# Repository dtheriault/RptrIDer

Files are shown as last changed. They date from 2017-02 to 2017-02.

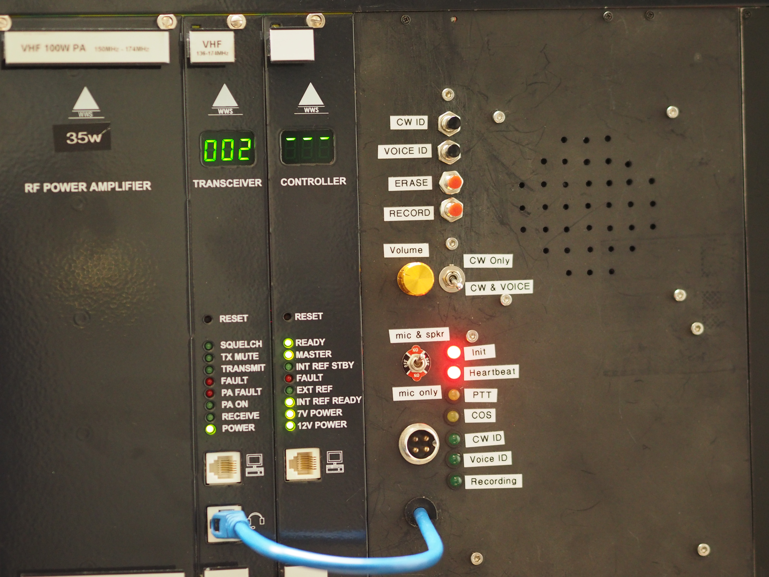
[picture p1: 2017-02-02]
Pics/P2020010.JPG

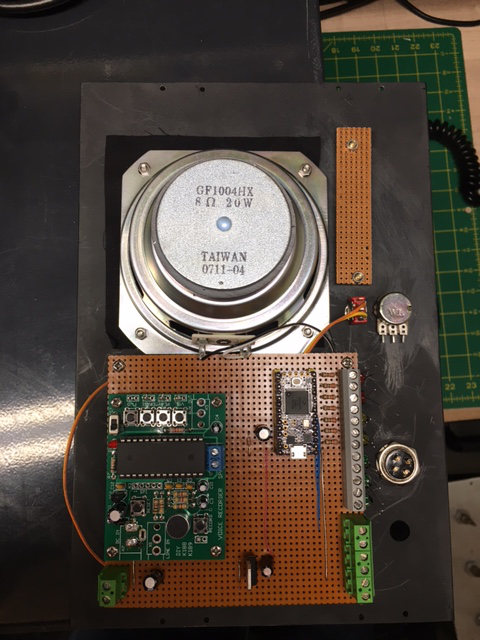
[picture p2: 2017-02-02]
Pics/IMG_0762.JPG

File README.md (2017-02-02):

# RptrIDer

Teensy3.2 Based Repeater Controller

This is a very simplistic repeater controller I built for Sherwin WB7NFX.
Included in the project is manual, schematic, eagle board files and the
Arduino sketch file for a Teensy3.2 board.

The repeater controller was designed to interface to a Westel DRB25 VHF
repeater.  This repeater did not have capability to ID per FCC Part 97 rules
and since the machine was to be used on the 2m ham band, this was a must.

Sherwin wanted the repeater to generate a Voice ID and provided me with a
small PCB that performed audio recording and playback.  I decided to build up
this board and have it controlled by a small ATtiny85 processor.  Shortly I
wanted to add CW support and have more input/outputs for buttons and LED's
so moved to an Teensy3.2 board I had purchased but had not found a project
to use it with.  A repeater controller seemed ideal.

Front panel was to have LED's to indicate status of the repeater and
controller operations.  When PTT, CW ID, Voice ID, Carrier Detect and status
for when the Voice Recording is erased or recorded.  There's also a heartbeat
and init status LED.

Interface to the repeater is via an RJ45 jack on the transceiver card.
There was an empty set of slots in the chassis for me to add a panel, speaker
microphone jack, LED's, buttons and switches and a volume control.  It also
mounts a home brew PCB that houses the Teensy and Voice ID boards.

The board is very simple 3 channel audio mixer with header for the Teensy3.2
and a voice ID board.  Uses standard header pins since that's what I had and
allowed me to debug this on the desk vs. connected to the repeater.

The Teensy3.2 is responsible for time keeping, generating a CW ID, detecting
inputs such as PTT, and front panel buttons and implements simplistic Carrier
Detect to know when the repeater is in use.  Westel did not have COS line
for me to use.  Power for the board is supplied by the transceiver card and
total current at 12v is around 150ma max.

There is a directory with photo's of the project, and if you search on
YouTube you can find a movie of the prototype in use during debug of the
project.

Special thanks goes to SV1DJG, Nick in Greece who developed the CW Beacon
sketch I leveraged into this project.

This project is available via GPL for your use.

Feel free to drop me an email if you have any questions on the project and
I'll try to answer them as best I can.  Please note, the code was quickly
developed and is probably still has a bug or two.

WB7NFX Repeater is operational in Chino Valley Az @ 144.570/145.170 Mhz with
PL of 100.0 Hz.

73,
Doug - NO1D

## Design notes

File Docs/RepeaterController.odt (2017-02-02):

# Introduction

The WB7NFX Repeater Controller is a module designed to support a Westell DRB25 VHF repeater. The controller consists of 3 components, a 2-board module and front panel containing speaker, LED’s and push button controls.

The controller interfaces with the VHF transceiver board via an RJ45 connector. The controller generates CW ID and Voice ID at 10m and 30m intervals respectively. The CW ID interval follows part 97 rules pertaining to Repeater Identification. Power is supplied from the VHF transceiver board.

The controller consists of a 3 channel audio mixer that takes CW, Voice and Microphone feed from the front panel and interfaces to the VHF repeater module via its Microphone input. Levels for each channel are made via trim pots on the controller module.

To maintain time/state information the controller utilizes a small micro-controller called a Teensy3.2 AVR. The micro-controller is responsible for driving PTT to the repeater and generates a Carrier Operated Squelch input to determine repeater activity. The micro-controller drives LED for status indication and senses push button controls from the microphone and push buttons on the front panel. The micro-controller also generates the CW ID which has been programmed via software. Updates to the software can be made via USB interface on the Teensy3.2 sub-module.

When the repeater is idle a Voice ID can be configured to be sent every 30m. When COS is first detected a CW ID is sent at 18wpm and again every 10m while the machine is active.

# Front Panel, Interconnect and Controls

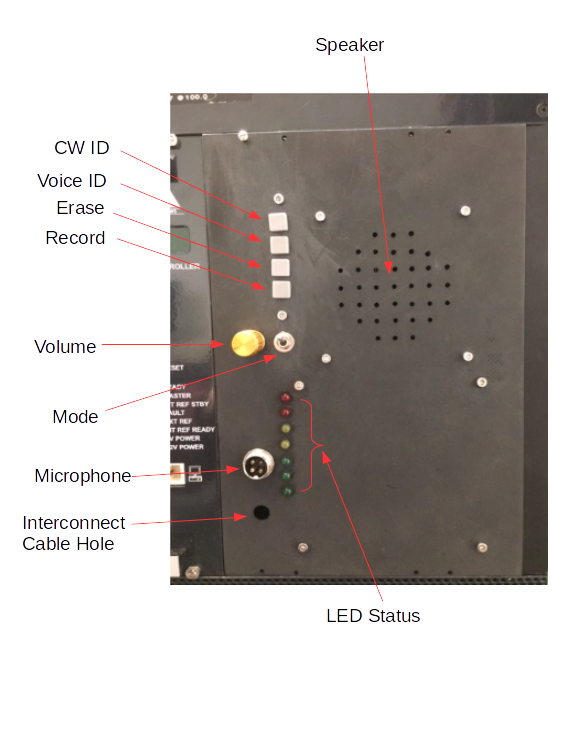
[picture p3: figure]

# Operation

Operation of the controller is simplistic. There are several buttons on the front panel which perform the following operations :

- CW ID – Sends CW ID which has been programmed into the software.
- Voice ID – Sends the Voice ID which has been recorded in the Voice ID board
- Erase – Erases the recorded Voice ID
- Record – Records a new Voice ID. Note that you must first Erase the stored ID before a new one is recorded. Recording of the message uses the front panel microphone however PTT is not required to be pressed.
- Mode – Toggles whether the controller sends CW ID only or Both Voice ID and CW ID. CW ID is sent after the 1st time the repeater goes active then again in 10m per part 97 rule. Voice ID is sent at 30m intervals when the repeater is not active.

The front panel contains a speaker and small audio amplifier with volume control. This allows to hear the repeater activity. When using the front panel microphone to transmit voice is not heard over the speaker.

Note : If using a handheld transceiver and volume is up you may hear feedback unless the microphone has been disconnected from the front panel or the volume is turned down enough to prevent feedback.

Front panel has 7 LED’s that represent status of the controller. They are as follows (top to bottom) :

LED | Description
INIT | Lights up when the setup function completes in software
HEARTBEAT | Pulses approx 1s intervals indicating main loop is operational
PTT | Microphone PTT is active
COS | Repeater Tx is busy, Carrier Operated Squelch via software
CW ID | CW ID is being sent
Voice ID | Voice ID is being sent
Recording | Recording new voice ID in process

# Schematic

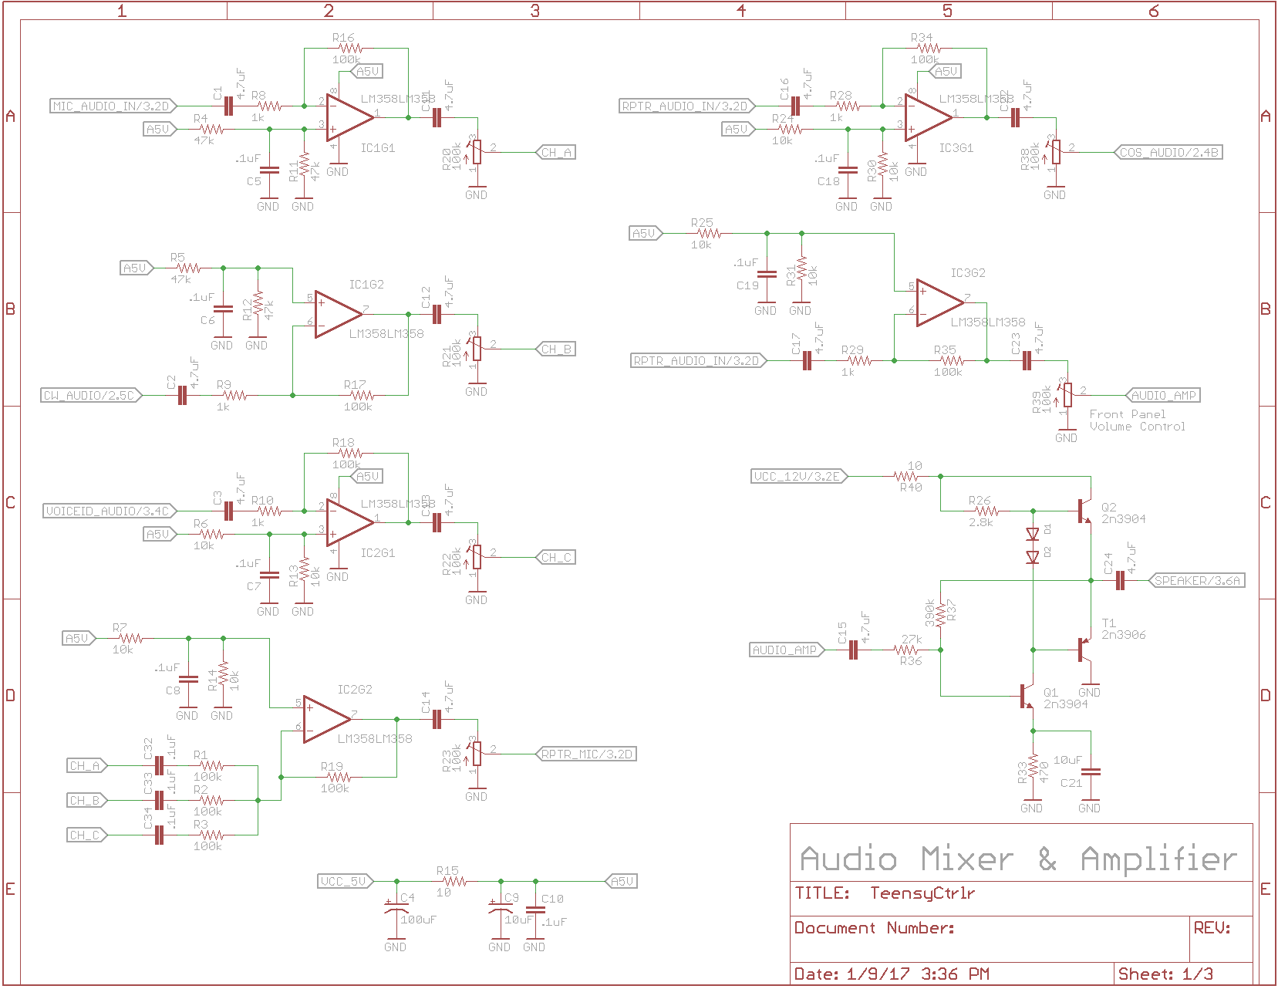
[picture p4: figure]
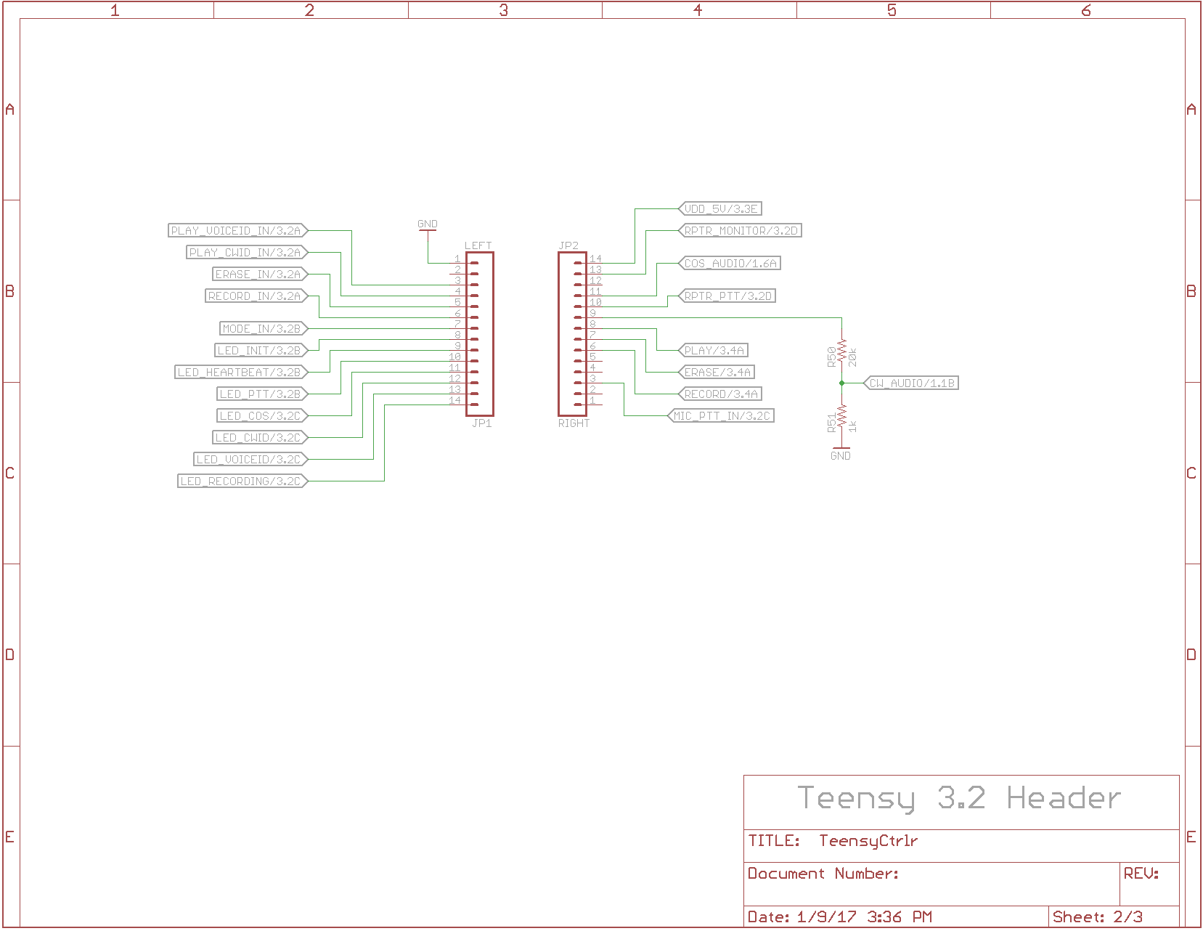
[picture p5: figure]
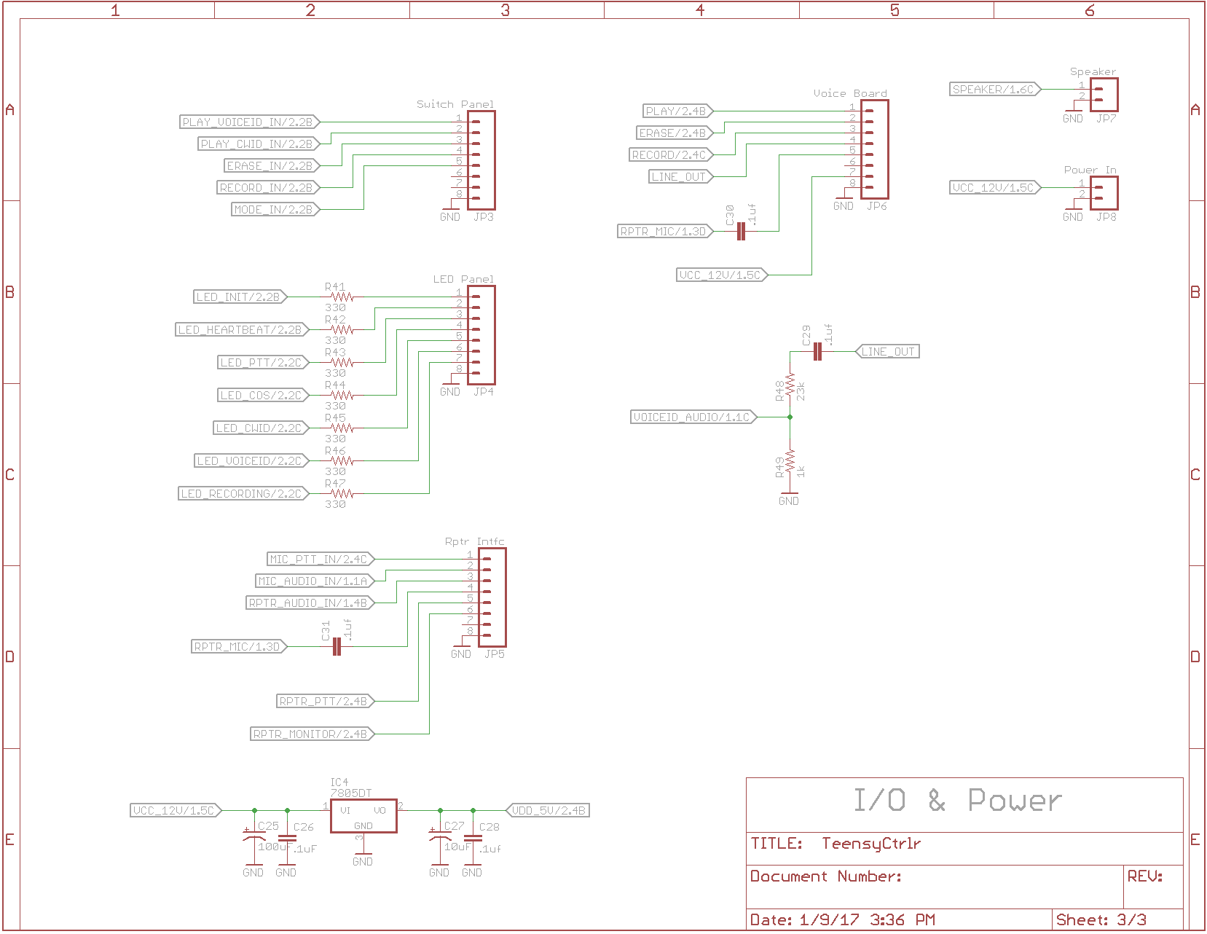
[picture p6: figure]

# Software

Software can be found at : https://github.com/dtheriault/TeensyRptrCtrlr

The software is offered under the GPL and is considered Open Source available for general use and modification following GPL agreement.

Software is written in C langage, and uses the Ardruino IDE supporting the Teensy3.2 AVR chipset.

Updates to the software are made using the micro USB connector on the Teensy3.2 module located on the controller module.

//

// File: TeensyRptrCtrlr.ino

//

// Author: NO1D - Doug Theriault

// Dated: 20170112

//

// Description:

//

// This sketch is a very basic/simple repeater ID controller which was developed

// for WB7NFX. The interface is to a Westel DRB25 VHF repeater however this

// software is generic and can be modified to fit other requirements.

//

// The software handles button presses to activate CW ID, Voice ID and record

// and erase functions and mode switch. In addition it outputs series of 7 LEDs

// to track state/function. It also outputs control lines to a Voice ID board

// and the repeater itself.

//

// Since the Westel Repeater did not have means to detect COS (carrier operated

// squelch) the repeaters audio is fed into a pin configured with ADC so its

// voltage can be read.

//

// The controller was based on Teensy3.2 board. I started with an ATiny85 but

// quickly ran out of pins as I wanted to add more/more features...

//

// References:

//

// The CW ID portion of the code was developed by SV1DJG which was a great start

// for me to get something working on an ATiny85 chip. Special thanks goes out

// to Nick for producing this software. I include his file header below.

//

// Bugs/Issues/ToDo:

//

// Ideally this would all be run off interrupts/timers. Someday perhaps.

// This is not a very powerful repeater controller. While it will ID per part 97

// rules, its been deployed only recently and may still contain bugs.

// There are some printf statements for debugging left in the code and do affect

// accuracy of the timing. You might need to modify delay loops when removing

// them.

//

// Hardware:

//

// Schematic for simple 3-channel audio mixer, 3-transistor audio amp, Teensy I/O

// LED's etc are available on github.

//

// Voice ID is handled by external board similar to:

// https://ludens.cl/Electron/voiceID/voiceID.html

//

// Contact info:

//

// email: no1d.doug@gmail.com

// repository: https://github.com/dtheriault/TeensyRptrCtrlr

//

// License:

//

// Copyright (C) 2017 Douglas Theriault - NO1D

//

// TeensyRptrCtrlr.ino is free software: you can redistribute it and/or modify

// it under the terms of the GNU General Public License as published by

// the Free Software Foundation, either version 3 of the License, or

// (at your option) any later version.

//

// TeensyRptrCtrlr.ino is distributed in the hope that it will be useful,

// but WITHOUT ANY WARRANTY; without even the implied warranty of MERCHANTABILITY

// or FITNESS FOR A PARTICULAR PURPOSE. See the GNU General Public License for

// more details.

//

// You should have received a copy of the GNU General Public License

// along with IDtimer.ino. If not, see <http://www.gnu.org/licenses/>.

//

//

////////////////////////////////////////////////

//

// A simple CW Blinker (aka LED Beacon)

// by SV1DJG (c.2016)

//

// This is a ultra simple blinker in CW for the

// digispark mini board (attiny85).

// change the led port if using a different

// board (e.g. Arduino)

//

// Just set your message into the msg array and you

// are ready to go.Make sure to use ONLY the set

// of the supported characters.

// the supported set of characters is capital

// letters,numbers and a few symbols.

//

// You can also modify the transmission speed by

// changing the speedWPM variable.

//

// HAVE FUN!!

//

// This code is provided as-is and may contain bugs!

//

// (codesize:1132 bytes + message length)

//

////////////////////////////////////////////////

#include <avr/pgmspace.h>

//

// PIN Definitions: Input and Outputs

//

#define PLAY_VOICE_IN 1 // Send the Voice ID, Play on Voice Bd

#define PLAY_CW_IN 2 // Send a CW ID from the Teensy

#define ERASE_IN 3 // Erase the Voice ID, Erase on Voice Bd

#define RECORD_IN 4 // Record New Voice ID, Record on Voice Bd

#define MODE_IN 5 // Toggle switch for CW only or CW & Voice ID

//

#define LED_INIT 6 // Setup has been executed, stays lit

#define LED_HEARTBEAT 7 // Loop interval, one second pulse

#define LED_PTT 8 // PTT is activated, Microphone front panel

#define LED_COS 9 // COS detected from Repeater Audio feed

#define LED_CWID 10 // CW ID in process

#define LED_VOICEID 11 // Voice ID in process

#define LED_RECORDING 12 // Recording new Voice ID in process

//

#define RPTR_MONITOR 14 // Repeater Monitor Active Low (not used)

#define PTT_IN 15 // Front Panel Microphone, Active Low

//

#define RECORD_OUT 18 // Button on Voice Bd

#define ERASE_OUT 19 // Button on Voice Bd

#define PLAY_OUT 20 // Button on Voice Bd

//

#define CW_AUDIO 21 // PWM Teensy output of CW Audio tone

#define PTT_OUT 22 // PTT to Repeater, Active Low

#define COS_IN 23 // Carrier Detect Input

//

//

//

// General Defines

//

#define CW_TONE 750 // CW ID Tone in Hertz

//

#define MODE_CW_ONLY 0 // Does not play Voice ID

#define MODE_BOTH 1 // Plays both Voice and CW ID's

//

// State Machine Defines

//

#define IDLE 1 // IDLE State

#define TIMING_CW 2 // Timer State: Detected COS/PTT

#define TIMING_VOICE 3 // Timer State: Detected COS/PTT

#define CWID 4 // CW ID: Send CW ID now, timer expired

#define VOICEID 5 // Voice ID: Send Voice ID

#define RPTR_ACTIVE 6 // Time COS/PTT been active

#define ID_FIRST 7 // First ID > 10m on first PTT/COS from IDLE period

//

// Timeouts are in seconds

//

#define CW_TIMEOUT 600 // Play CW ID every 10m after COS or PTT go active

#define VOICE_TIMEOUT 1800 // Play Voice ID every 30m when IDLE

#define COS_TIMEOUT 300 // COS/PTT 3m timeout

#define VID_TIMEOUT 1200 // 20m after CWID, if we're idle, we VoiceID

//

// All delays are in ms

//

#define RECORDING_DELAY 10000 // Record for 10s

#define ERASE_DELAY 10000 // Erase for 10s

#define VOICEID_DELAY 10000 // 10s for voice id to play

#define PTT_DELAY 1500 // 1.5s PTT delay

#define COS_DELAY 100 // delay 100ms between consecutive COS ADC reads

//

#define LED_OFF LOW

#define LED_ON HIGH

#define TRUE 0

#define FALSE 1

// this defines the keying level and provides a quick way to change the keying method.

// when we use a LED we need HIGH to turn the LED on and LOW to turn the LED off

// but if we select to connect an external switching hardware , this may need to be reversed

#define MORSE_KEY_DOWN HIGH

#define MORSE_KEY_UP LOW

// delay before repeating the message (in Ms)

#define repeatDelayMs 300000

// transmission speed (in words per minute)

#define speedWPM 18

// element duration is according to Farnsworth Technique

// see : http://www.arrl.org/files/file/Technology/x9004008.pdf

#define dotDuration 1200 / speedWPM // element duration in milliseconds

#define dashDuration dotDuration * 3

#define interSymbolDuration dotDuration

#define interCharDuration dotDuration * 3

#define interWordDuration dotDuration * 7

//

// Global Variables Here

//

boolean mic_ptt;

boolean play_voice;

boolean play_cw;

boolean erase_voice;

boolean record;

boolean voice_bd_reset;

int mode;

int state;

int last_state;

int cw_timer;

int voice_timer;

int activity_timer;

int last_id;

int cos_in;

boolean last_ptt;

boolean last_cos;

char dState[8][16] =

{

"UNKNOWN",

"IDLE",

"TIMING CW",

"TIMING VOICE",

"CW ID",

"VOICE ID",

"RPTR ACTIVE",

"ID FIRST"

};

//////////////////////////////////////////////////////////////////////////////////////////////

//

// this is the beacon message (only capital letters, numbers and a few symbols - see below)

//

//////////////////////////////////////////////////////////////////////////////////////////////

//char const msg[] = "TEST DE SV1DJG";

char const msg[] = "DE WB7NFX/R";

char const msgTimeout[] = "TIMEOUT";

//

// Morse code table

// ----------------

// Morse code elements are variable length and transmitted Msb first.

// we need to know the length of each element so we save

// it along with the element as the first part of the pair in the table.

//

// Each element is made up from 1's and 0's where:

// 1 means DOT

// 0 mean DASH

// for example, A is DOT-DASH which is translated to 10.

// B is DASH-DOT-DOT-DOT which is translated to 0111 etc.

// these are encoded as binary values and paired with their length

// for example

// A -> 2,B10

// B -> 4,B0111

// etc

//

// table of elements for Morse cose numbers do not follow this as all elements are 5 digits long

// (so we save space in the symbol table)

//

byte const letters[] PROGMEM =

{

2,B10, // A

4,B0111, // B

4,B0101, // C

3,B011, // D

1,B1, // E

4,B1101, // F

3,B001, // G

4,B1111, // H

2,B11, // I

4,B1000, // J

3,B010, // K

4,B1011, // L

2,B00, // M

2,B01, // N

3,B000, // O

4,B1001, // P

4,B0010, // Q

3,B101, // R

3,B111, // S

1,B0, // T

3,B110, // U

4,B1110, // V

3,B100, // W

4,B0110, // X

4,B0100, // Y

4,B0011, // Z

};

byte const numbers[] PROGMEM =

{

B00000, // 0

B10000, // 1

B11000, // 2

B11100, // 3

B11110, // 4

B11111, // 5

B01111, // 6

B00111, // 7

B00011, // 8

B00001, // 9

};

byte const symbols[] PROGMEM =

{

6,B101010, // Full-stop (period)

6,B001100, // Comma

6,B110011, // Question mark (query)

5,B01101 , // Slash

5,B01110 , // Equals sign

};

// transmits a morse element (either a dot or a dash)

void sendSymbol(boolean sendDot)

{

digitalWrite(LED_CWID, MORSE_KEY_DOWN);

tone(CW_AUDIO, CW_TONE);

delay(sendDot ? dotDuration : dashDuration);

digitalWrite(LED_CWID, MORSE_KEY_UP);

noTone(CW_AUDIO);

}

// transmits an ASCII character in Morse Code

void sendCharacter(char c)

{

byte numberOfBits = 0;

byte elementCode = 0;

if (c >= 'A' && c <='Z')

{

int elementIndex = (int)(c-'A');

numberOfBits = pgm_read_byte(&letters[elementIndex * 2]);

elementCode = pgm_read_byte(&letters[elementIndex * 2 + 1]);

}

else if (c >= '0' && c <='9')

{

int elementIndex = (int)(c-'0');

numberOfBits = 5;

elementCode = pgm_read_byte(&numbers[elementIndex]);

}

else if (c == ' ')

{

// adjust delay because we have already "waited" for a character separation duration

// NOTE:this delay will not be 100% accurate if the first character in the message is SPACE

delay(interWordDuration-interCharDuration);

}

else

{

int elementIndex = -1;

if (c == '.') elementIndex = 0;

else if (c == ',') elementIndex = 1;

else if (c == '?') elementIndex = 2;

else if (c == '/') elementIndex = 3;

else if (c == '=') elementIndex = 4;

if (elementIndex != -1)

{

numberOfBits = pgm_read_byte(&symbols[elementIndex * 2]);

elementCode = pgm_read_byte(&symbols[elementIndex * 2 + 1]);

}

}

if (numberOfBits > 0)

{

byte mask = 0x01 << (numberOfBits - 1);

while (numberOfBits > 0 )

{

sendSymbol((elementCode & mask) == mask);

delay(interSymbolDuration);

mask = mask >> 1;

--numberOfBits;

}

// adjust delay because we have already "waited" for a dot duration

delay(interCharDuration - interSymbolDuration);

}

}

// transmits an ASCII message in Morse Code

void sendCWID(const char* msg)

{

// trigger PTT so we send ID over repeater

digitalWrite(PTT_OUT, LOW);

digitalWrite(LED_PTT, LED_ON);

delay(PTT_DELAY);

while (*msg)

sendCharacter(*msg++);

delay(PTT_DELAY);

// turn off PTT at the end

digitalWrite(PTT_OUT, HIGH);

digitalWrite(LED_PTT, LED_OFF);

}

// transmits Voice ID via external board

void sendVoiceID()

{

Serial.print("Sending Voice ID\n");

digitalWrite(PTT_OUT, LOW);

digitalWrite(LED_PTT, LED_ON);

delay(PTT_DELAY);

digitalWrite(PLAY_OUT, LOW);

digitalWrite(LED_VOICEID, LED_ON);

// TODO: Ideally we want program to continue while output is low

// as believe voice play stops when we toggle back high

delay(VOICEID_DELAY);

digitalWrite(PLAY_OUT, HIGH);

digitalWrite(LED_VOICEID, LED_OFF);

delay(PTT_DELAY);

digitalWrite(PTT_OUT, HIGH);

digitalWrite(LED_PTT, LED_OFF);

Serial.print("End Voice ID\n");

}

//

// Reset the external Voice ID board

//

void resetVoiceBd()

{

// digitalWrite(RESET_OUT, LOW);

delay(500);

// digitalWrite(RESET_OUT, HIGH);

}

//

// Erase stored Voice ID

//

void eraseVoice()

{

digitalWrite(ERASE_OUT, LOW);

delay(ERASE_DELAY);

digitalWrite(ERASE_OUT, HIGH);

Serial.print("Voice ID Erased\n");

}

//

// Record New Voice ID

//

void recordVoiceID()

{

// first erase Voice ID

eraseVoice();

// Enable recording for max of 7 seconds

digitalWrite(LED_RECORDING, LOW);

digitalWrite(RECORD_OUT, LOW);

delay(RECORDING_DELAY);

digitalWrite(RECORD_OUT, HIGH);

// delay a bit between operations

delay(2000);

// Now play without transmitting

digitalWrite(PLAY_OUT, LOW);

delay(VOICEID_DELAY);

// Turn off LED indicator at end of recording

digitalWrite(LED_RECORDING, HIGH);

Serial.print("Voice ID Recorded\n");

}

//

// readCOS()

//

boolean readCOS()

{

int rValue = 0;

rValue = analogRead(COS_IN);

delay(COS_DELAY);

rValue += analogRead(COS_IN);

rValue = rValue/2;

// Serial.printf("COS: %3d\n", rValue);

if (rValue > 30) return HIGH;

return LOW;

}

//

// readInputs()

//

void readInputs()

{

mic_ptt = digitalRead(PTT_IN);

play_voice = digitalRead(PLAY_VOICE_IN);

play_cw = digitalRead(PLAY_CW_IN);

erase_voice = digitalRead(ERASE_IN);

record = digitalRead(RECORD_IN);

mode = digitalRead(MODE_IN);

cos_in = readCOS();

}

//

// execCommands()

//

void execCommands()

{

// Low Priority: Handle Front Panel Buttons

//

if (play_cw == LOW)

state = CWID;

else if (play_voice == LOW)

state = VOICEID;

// if (voice_bd_reset == LOW)

// resetVoiceBd();

if (record == LOW)

recordVoiceID();

else if (erase_voice == LOW)

eraseVoice();

// Med Priority: Handle COS input

//

if (cos_in == HIGH) {

if (last_cos == LOW)

Serial.print("COS Active\n");

last_cos = HIGH;

// light the COS LED

digitalWrite(LED_COS, LED_ON);

}

else {

if (last_cos == HIGH)

Serial.print("COS Deactivated\n");

last_cos = LOW;

digitalWrite(LED_COS, LED_OFF);

}

// High Priority: Handle PTT

//

if (mic_ptt == LOW) {

if (last_ptt == HIGH)

Serial.print("PTT Active\n");

last_ptt = LOW;

digitalWrite(LED_PTT, LED_ON);

digitalWrite(PTT_OUT, LOW);

}

else {

digitalWrite(LED_PTT, LED_OFF);

digitalWrite(PTT_OUT, HIGH);

if (last_ptt == LOW)

Serial.print("PTT Deactivated\n");

last_ptt = HIGH;

}

// Serial.printf("execCmd: [COS]: %d, [PTT]: %d\n", cos_in, mic_ptt);

}

//

// Initialization Function - executed once

//

void setup()

{

int x = 0;

int value = 0;

// Initilize Pins

//

pinMode(PTT_IN, INPUT_PULLUP);

pinMode(PLAY_VOICE_IN, INPUT_PULLUP);

pinMode(PLAY_CW_IN, INPUT_PULLUP);

pinMode(ERASE_IN, INPUT_PULLUP);

pinMode(RECORD_IN, INPUT_PULLUP);

pinMode(MODE_IN, INPUT_PULLUP);

analogReference(DEFAULT);

for (x = 0; x < 100; x++) {

value += analogRead(COS_IN);

}

pinMode(LED_INIT, OUTPUT);

pinMode(LED_HEARTBEAT, OUTPUT);

pinMode(LED_PTT, OUTPUT);

pinMode(LED_COS, OUTPUT);

pinMode(LED_CWID, OUTPUT);

pinMode(LED_VOICEID, OUTPUT);

pinMode(LED_RECORDING, OUTPUT);

// pinMode(CW_AUDIO, ????);

pinMode(PTT_OUT, OUTPUT);

pinMode(PLAY_OUT, OUTPUT);

pinMode(RECORD_OUT, OUTPUT);

pinMode(ERASE_OUT, OUTPUT);

// pinMode(RESET_OUT, OUTPUT);

// preset digital outputs

digitalWrite(PTT_OUT, HIGH);

digitalWrite(PLAY_OUT, HIGH);

digitalWrite(RECORD_OUT, HIGH);

digitalWrite(ERASE_OUT, HIGH);

// Initialize State Machine to IDLE

//

state = IDLE;

last_state = DEFAULT;

// Voice_Bd_Reset the timer counts

//

cw_timer = CW_TIMEOUT;

voice_timer = VOICE_TIMEOUT;

activity_timer = COS_TIMEOUT;

last_id = CW_TIMEOUT;

// voice_bd_reset globals

//

play_voice = HIGH;

play_cw = HIGH;

erase_voice = HIGH;

record = HIGH;

mode = MODE_BOTH;

voice_bd_reset = HIGH;

// initialize carrier operated squelch

//

cos_in = 0;

mic_ptt = HIGH;

// initialize states for printing

//

last_ptt = HIGH;

last_cos = LOW;

// Flash LED's during Init

//

digitalWrite(LED_INIT, LED_ON);

digitalWrite(LED_HEARTBEAT, LED_ON);

digitalWrite(LED_PTT, LED_ON);

digitalWrite(LED_COS, LED_ON);

digitalWrite(LED_CWID, LED_ON);

digitalWrite(LED_VOICEID, LED_ON);

digitalWrite(LED_RECORDING, LED_ON);

delay(2000);

digitalWrite(LED_INIT, LED_OFF);

digitalWrite(LED_HEARTBEAT, LED_OFF);

digitalWrite(LED_PTT, LED_OFF);

digitalWrite(LED_COS, LED_OFF);

digitalWrite(LED_CWID, LED_OFF);

digitalWrite(LED_VOICEID, LED_OFF);

digitalWrite(LED_RECORDING, LED_OFF);

delay(2000);

// Leave this LED on at end of INIT function

digitalWrite(LED_INIT, LED_ON);

Serial.begin(9600);

}

// Main Repeater Controller Loop

//

// Description:

//

// This routine will loop endlessely executing a simple state machine

// that performs necessary ID'ng of the 2m repeater for Part 97 rules.

// When the repeater is idle, every 30m the repeater will key a voice ID

// board to play a Voice ID message. If from IDLE, the repeater generates

// transmission, Carrier Detect is determined at which time an ID will be

// sent when PTT is non-active. Then, 10m later a CW Id will be sent.

//

// The routine calls series of functions to read input from some switches,

// from the PTT and Monitor lines to perform specific actions such as

// recording a message, playing a Voice or CW Id or erasing a Voice ID.

//

// Note: Currently the CW Id is burned into the code. User must keep the

// voice ID same as CW Id.

//

// See the design document for schematic and details on operational control.

//

void loop()

{

// Read Inputs

readInputs();

// Execute FrontPanel commands

execCommands();

// Execute State Machine

switch (state)

{

case IDLE:

last_state = IDLE;

// reset timeout counters

cw_timer = CW_TIMEOUT;

voice_timer = VOICE_TIMEOUT;

activity_timer = COS_TIMEOUT;

state = TIMING_VOICE;

break;

case TIMING_CW:

last_state = TIMING_CW;

if (--cw_timer <= 0)

state = CWID;

else if ((mic_ptt == LOW) || (cos_in == HIGH)) {

state = RPTR_ACTIVE;

activity_timer = COS_TIMEOUT;

}

break;

case TIMING_VOICE:

last_state = TIMING_VOICE;

// if we've timed out, immediately send appropriate ID

if (--voice_timer <= 0) {

if (mode == MODE_BOTH)

state = VOICEID;

else

state = IDLE;

}

// Check to see if Repeater has gone active

else if ((mic_ptt == LOW) || (cos_in == HIGH)) {

if (last_id >= CW_TIMEOUT) {

state = ID_FIRST;

last_id = 0;

}

else

state = RPTR_ACTIVE;

}

break;

case ID_FIRST:

voice_timer = VOICE_TIMEOUT;

last_state = ID_FIRST;

if ((mic_ptt == HIGH) && (cos_in == LOW)) {

sendCWID(msg);

activity_timer = COS_TIMEOUT;

state = RPTR_ACTIVE;

last_id = 0;

}

else if (--activity_timer <= 0) {

Serial.printf("Sending Timeout Msg\n");

sendCWID(msgTimeout);

sendCWID(msg);

activity_timer = COS_TIMEOUT;

state = RPTR_ACTIVE;

last_id = 0;

}

break;

case RPTR_ACTIVE:

last_state = RPTR_ACTIVE;

if ((mic_ptt == HIGH) && (cos_in == LOW)) {

state = TIMING_CW;

activity_timer = COS_TIMEOUT;

}

else if (--activity_timer <= 0) {

Serial.printf("Sending Timeout Msg\n");

sendCWID(msgTimeout);

activity_timer = COS_TIMEOUT;

}

else if (--cw_timer == 0) {

state = CWID;

}

break;

case CWID:

Serial.print("CW ID\n");

last_state = CWID;

sendCWID(msg);

last_id = 0;

state = IDLE;

break;

case VOICEID:

Serial.print("VOICE ID\n");

last_state = VOICEID;

sendVoiceID();

state = IDLE;

break;

default:

break;

}

// This counter keeps track of last time we ID'd

++last_id;

//

// Blinky Heartbeat LED

//

digitalWrite(LED_HEARTBEAT, LED_ON);

// wait and repeat

delay(500);

digitalWrite(LED_HEARTBEAT, LED_OFF);

// wait and repeat

delay(400);

Serial.printf("DEBUG: last state: %s, new state: %s, cwtmr=%d, atmr=%d, vtmr=%d, last_id: %d\n", dState[last_state], dState[state], cw_timer, activity_timer, voice_timer, last_id);

}

WB7NFX Repeater Project 10/01/17 13:17:35

by Doug Theriault – NO1D 2 of 20

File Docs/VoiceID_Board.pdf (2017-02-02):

# Voice identifier for a repeater station

When VHF FM
became
commonplace
among Chilean
hams in the
1970s, a
considerable
number of
repeater stations
were set up. Most
of these used
either RPT
Electronics
equipment, or the
VHF Engineering
repeater, along
with Wacom
duplexers.

The VHF
Engineering
repeater, pictured
here upside down, came from the factory with a CW identifier, which was programmed by soldering a lot of diodes in a matrix to form the station's callsign. Back in its day, it certainly fullfilled its purpose. But nowadays many hams don't know Morse code, enforcement officers know it even less, and so CW identifiers have become a beeping nuisance rather than a useful device. The CW identifier of these repeaters is configured in such a way that when the time for identifying comes, it will happily transmit the ID on top of any station using the repeater at that moment! That's pretty rude, I would say...

Several hams have told me that they can't leave their radios on a repeater frequency, because while their wifes would tolerate the occasional call or conversation, a sudden tirade of high pitched Morse beeping was definitely beyond their tolerance level! That's why repeaters set up later, such as in the 1990s, often used voice identifiers.

Except for their beeping nuisance, the old VHF Engineering repeaters still work pretty well, and so I was asked by Radio Club Temuco to upgrade them to voice ID. I designed a little voice ID module that is a direct drop-in replacement for the original VHF Engineering CWID module. It uses the ISD1740 voice recorder chip, in a very simple circuit. It can record an ID message more than 30 seconds long, which is far more than required. And it is a polite identifier: When time for identifying comes, it patiently waits for the repeater's user to stop transmitting, and only then it transmits its ID.

While I designed this module specifically for the VHF Engineering repeater, it can be used in many other repeaters with few or perhaps no modifications.

Voice identifier for a repeater station | https://ludens.cl/Electron/voiceID/voiceID.html
1 of 3 | 12/06/2016 10:57 AM

You
can
click
on
the

schematic diagram to get a high resolution version, which will be fine for printing.

The ISD1740 is used as a down-to-basics pushbutton-controlled recorder, fitted with its own electret microphone, and a timer was added to set the ID interval. Two transistors provide the inverting interfaces needed to connect this circuit to the VHF Engineering repeater.

I did not include a potentiometer for setting the output level, as the repeater has more than enough level setting pots. If you want to include one, it's easy to do so. Just place it over the 330 Ohm resistor. Any value from 1k to 10k should be fine.

There is a small amount of DC on the output. In applications where this is troublesome, add a coupling capacitor.

The TLC555 timer IC used here is a CMOS replacement for the ubiquitous NE555. Don't use the NE555, because it might not be able to work with the high impedance timing network required for the ID time. With the values shown here, the ID interval is slightly more than 4 minutes, and it can be lengthened, if desired, by increasing the value of the 6.8 megaohm resistor, or of the 47uF tantalum capacitor. You might have success using an aluminium electrolytic capacitor in place of the tantalum, but it depends on how low its leakage is. A tantalum cap is a safer bet.

This circuit will play the ID when the COR input goes high, if the ID interval has elapsed. While it plays, the PTT output is high. The COR module of the repeater takes care of sending the COR signal, and tying the ID module's PTT output into the TX control and tail circuits.

To record an ID message, first the ERASE button is pressed, to delete the existing ID message, if any, and then the RECORD button is pressed and held while speaking the message into the microphone. To test the message, without waiting for the ID interval to complete, the repeater is activated and the TEST button is pressed before the repeater drops.

The ISD chip can retain the recorded message for longer than a repeater's lifetime, so there should be no worry about this.

I was too lazy to
design a printed
circuit board, so I
used a piece of
universal board to
assemble it. It's
not as beautiful as
a true PCB, but
works as well.
The board is
much smaller
than the
repeater's original
CW identifier, and
uses two of the
original four
mounting posts. It
uses the same
connecting wires.
So it's really a
drop-in
replacement.

I used 1/8 watt
resistors,
removed from junked video tape recorders. Except for the two ICs, the electret microphone and the board, all of the parts were recycled from old equipment. I mean, a 35 year old repeater doesn't need all new components for such an addition, right? ;-)

The repeater has its AC power switch, with exposed connections, located very close to the ID board (left edge of this photo). To keep any button-pressing fingers from accidentally drawing some undue current from the power switch, I coated the exposed connections with hot melt glue. There are too few hams left, so we shouldn't electrocute any...

Back to the homo ludens electronicus page.

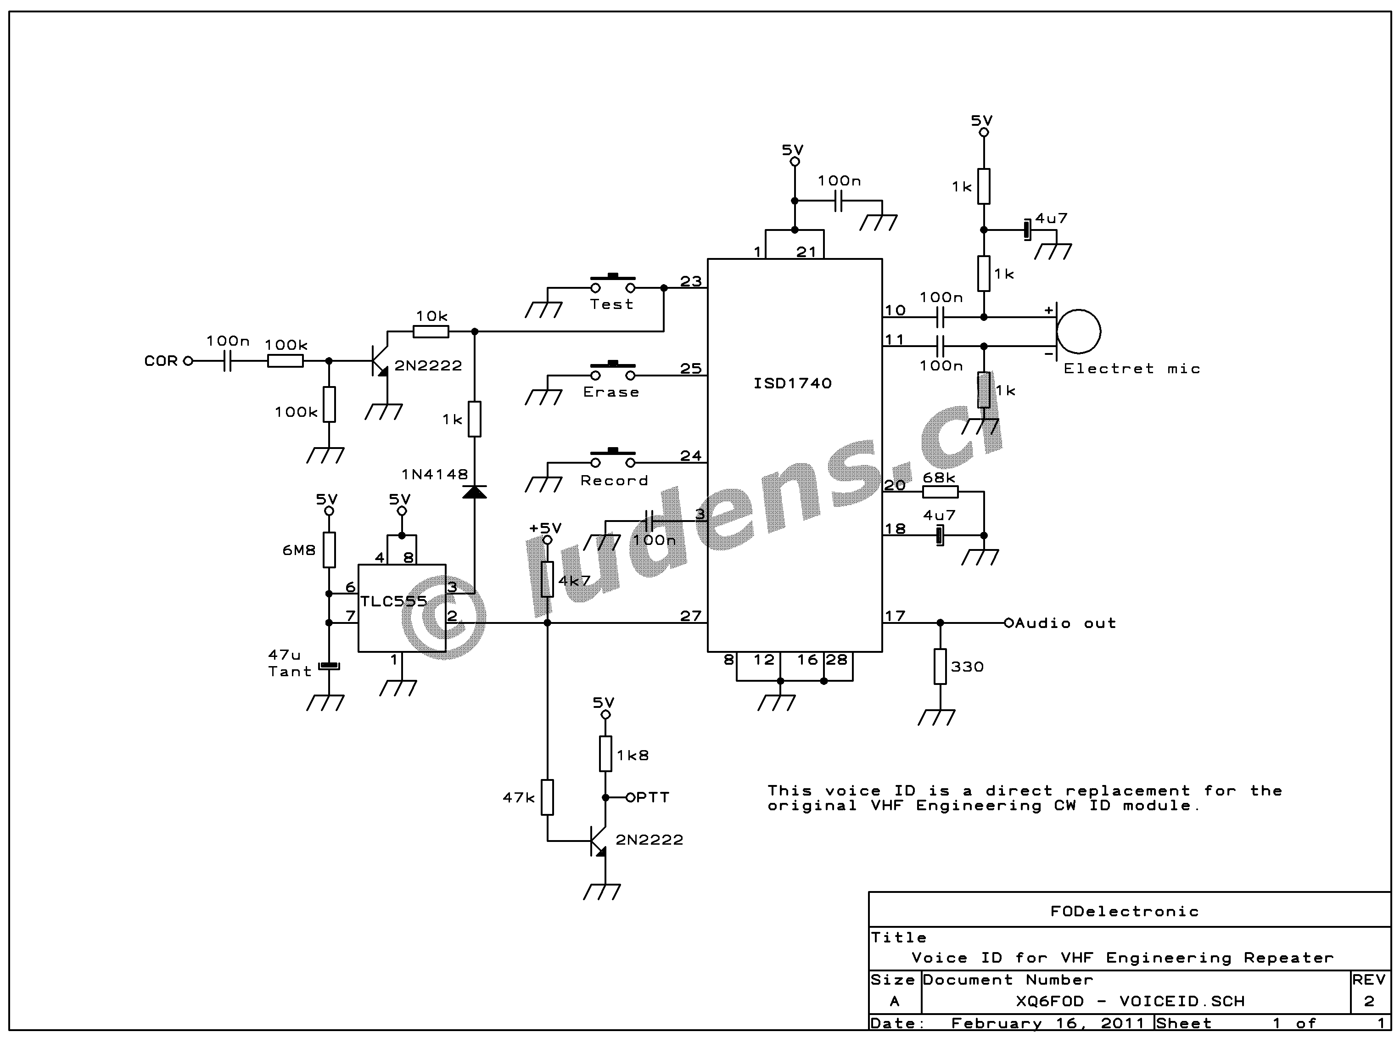
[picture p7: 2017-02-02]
Pics/VOICEID.png

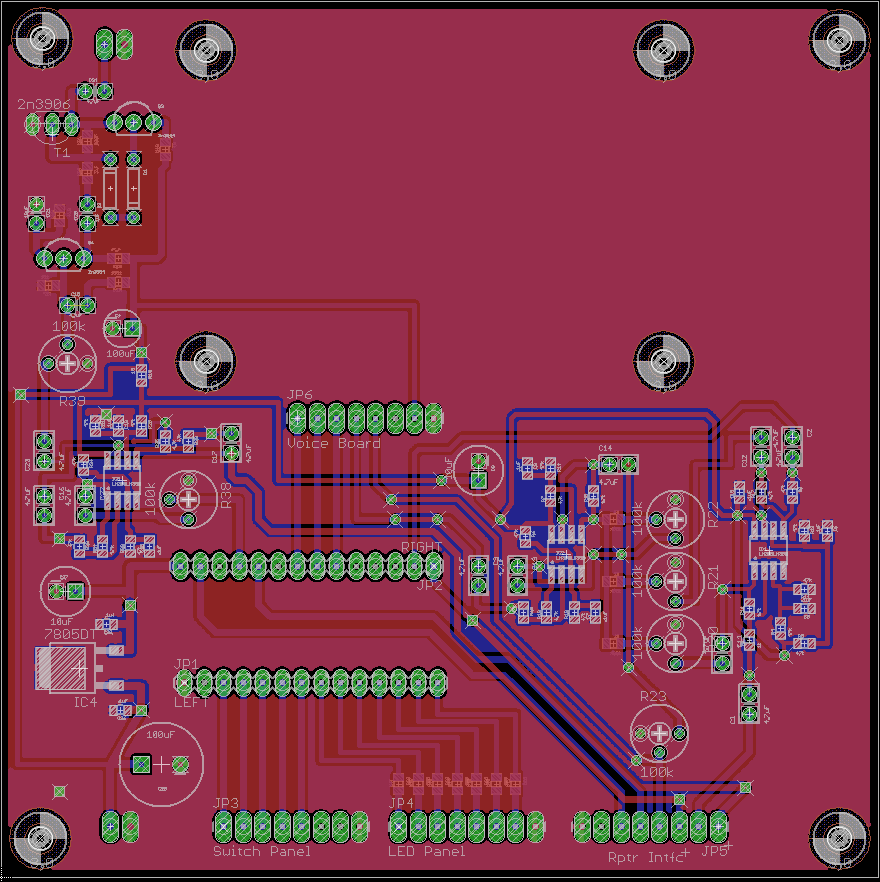
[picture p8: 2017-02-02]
Pics/1stPassLayout.png

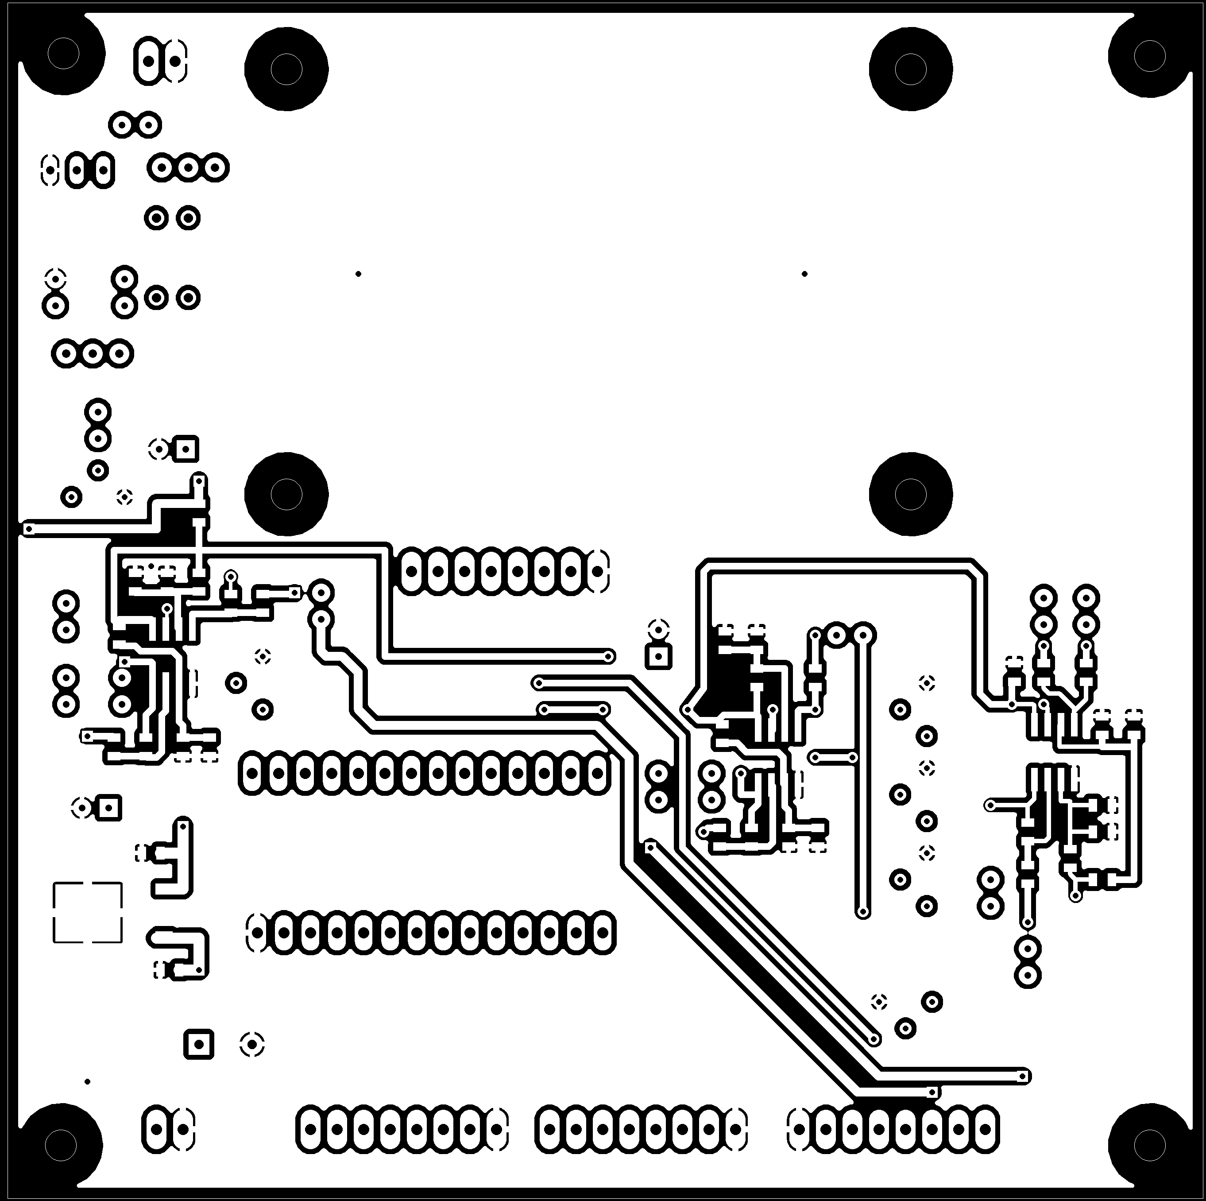
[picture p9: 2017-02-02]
Board/TopSide.png

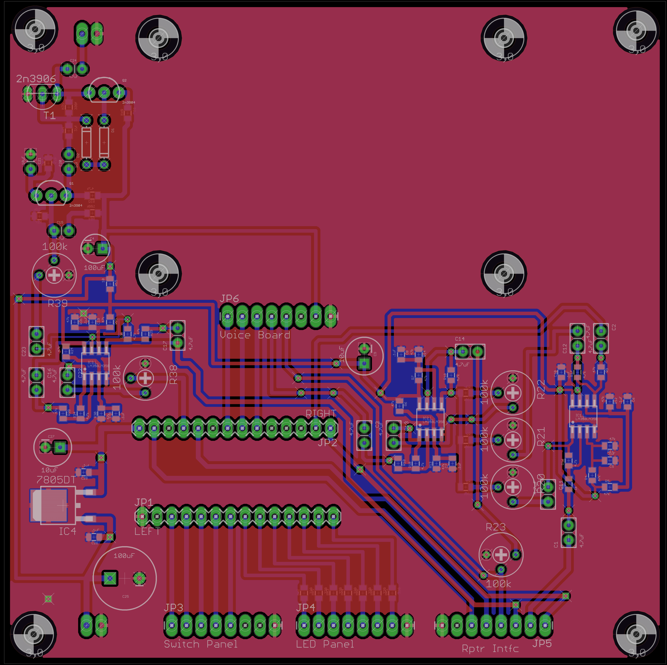
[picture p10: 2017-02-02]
Board/1stPass.png

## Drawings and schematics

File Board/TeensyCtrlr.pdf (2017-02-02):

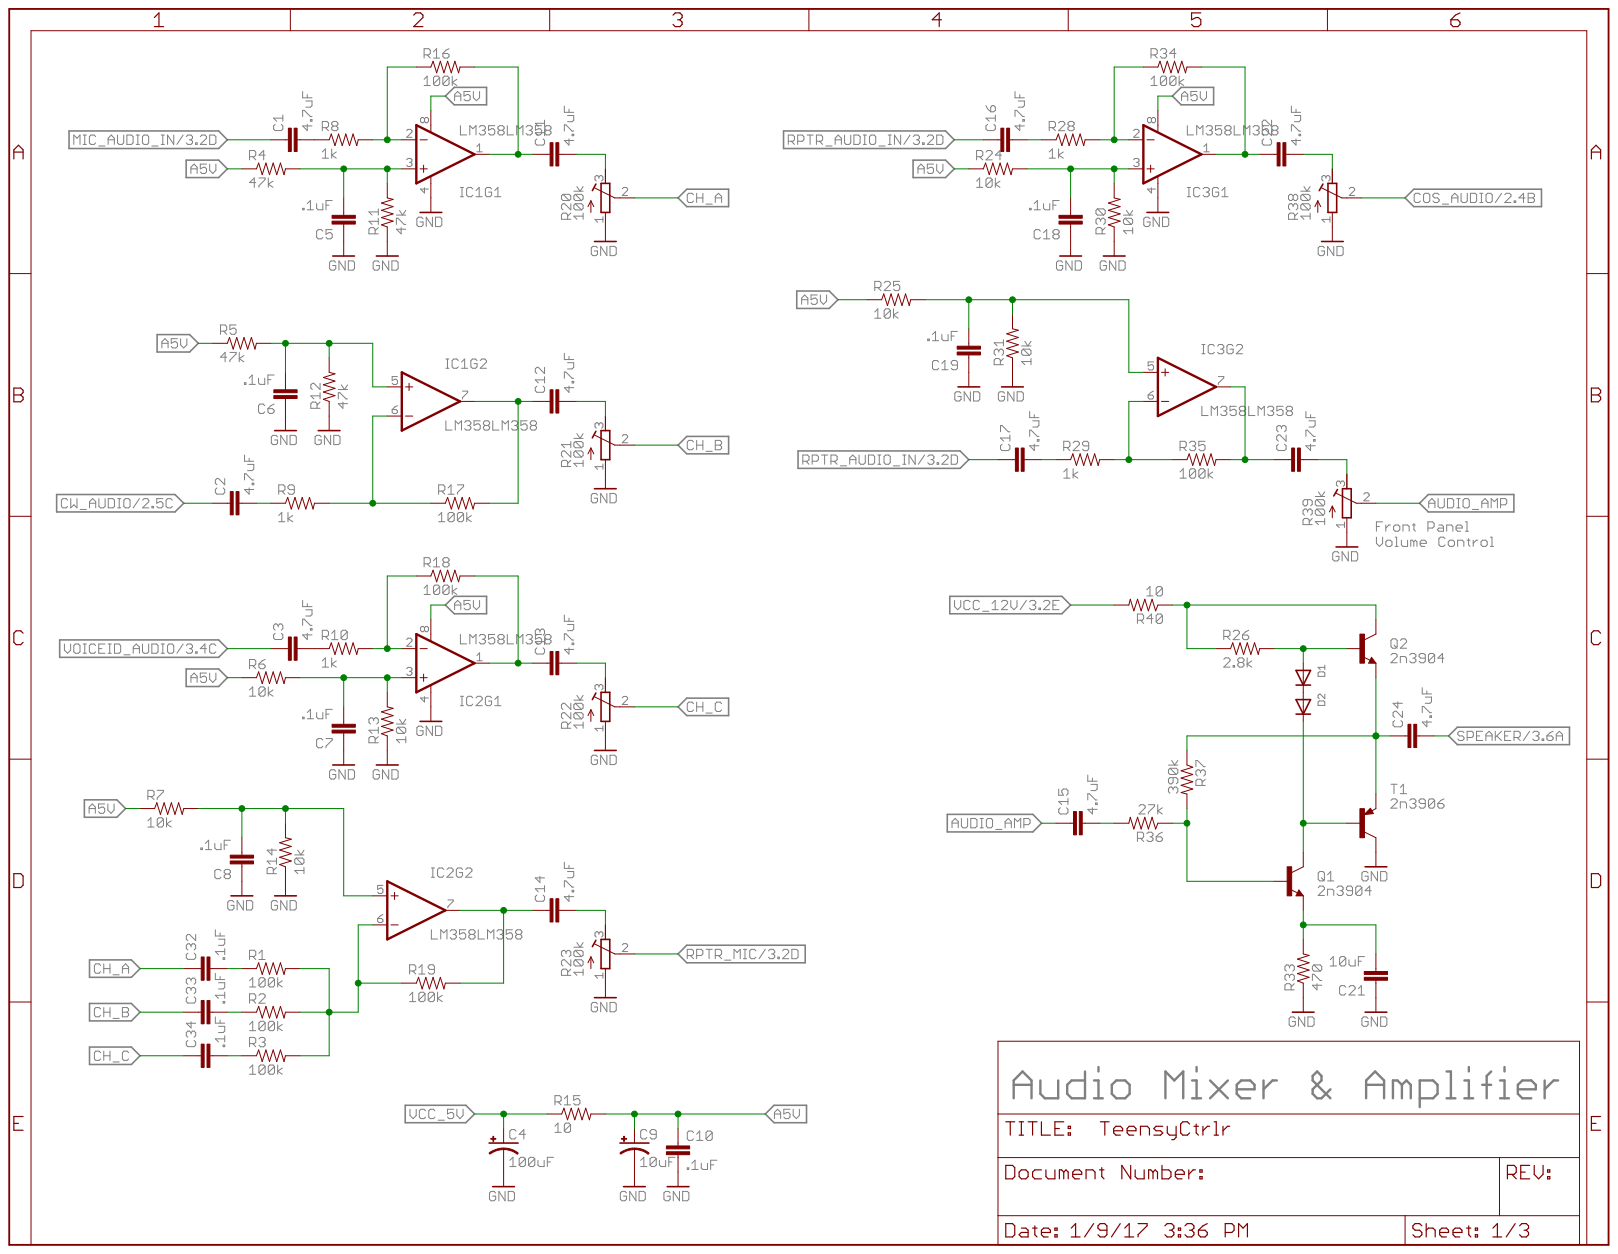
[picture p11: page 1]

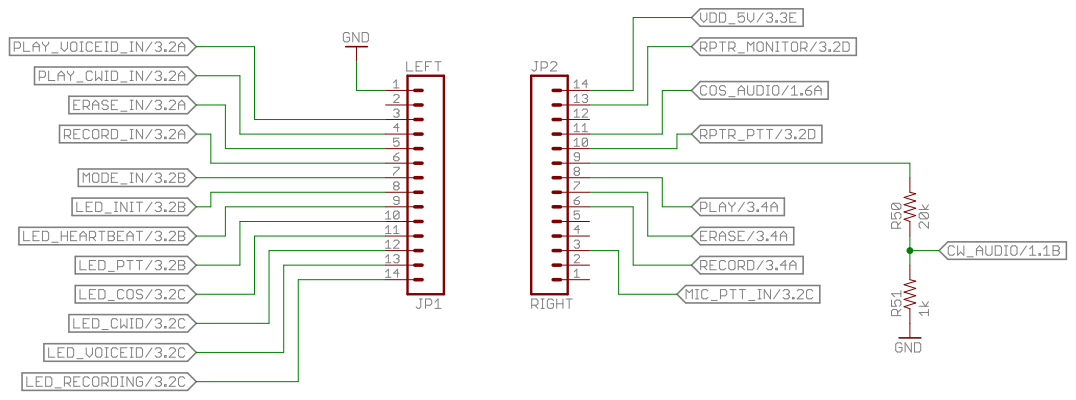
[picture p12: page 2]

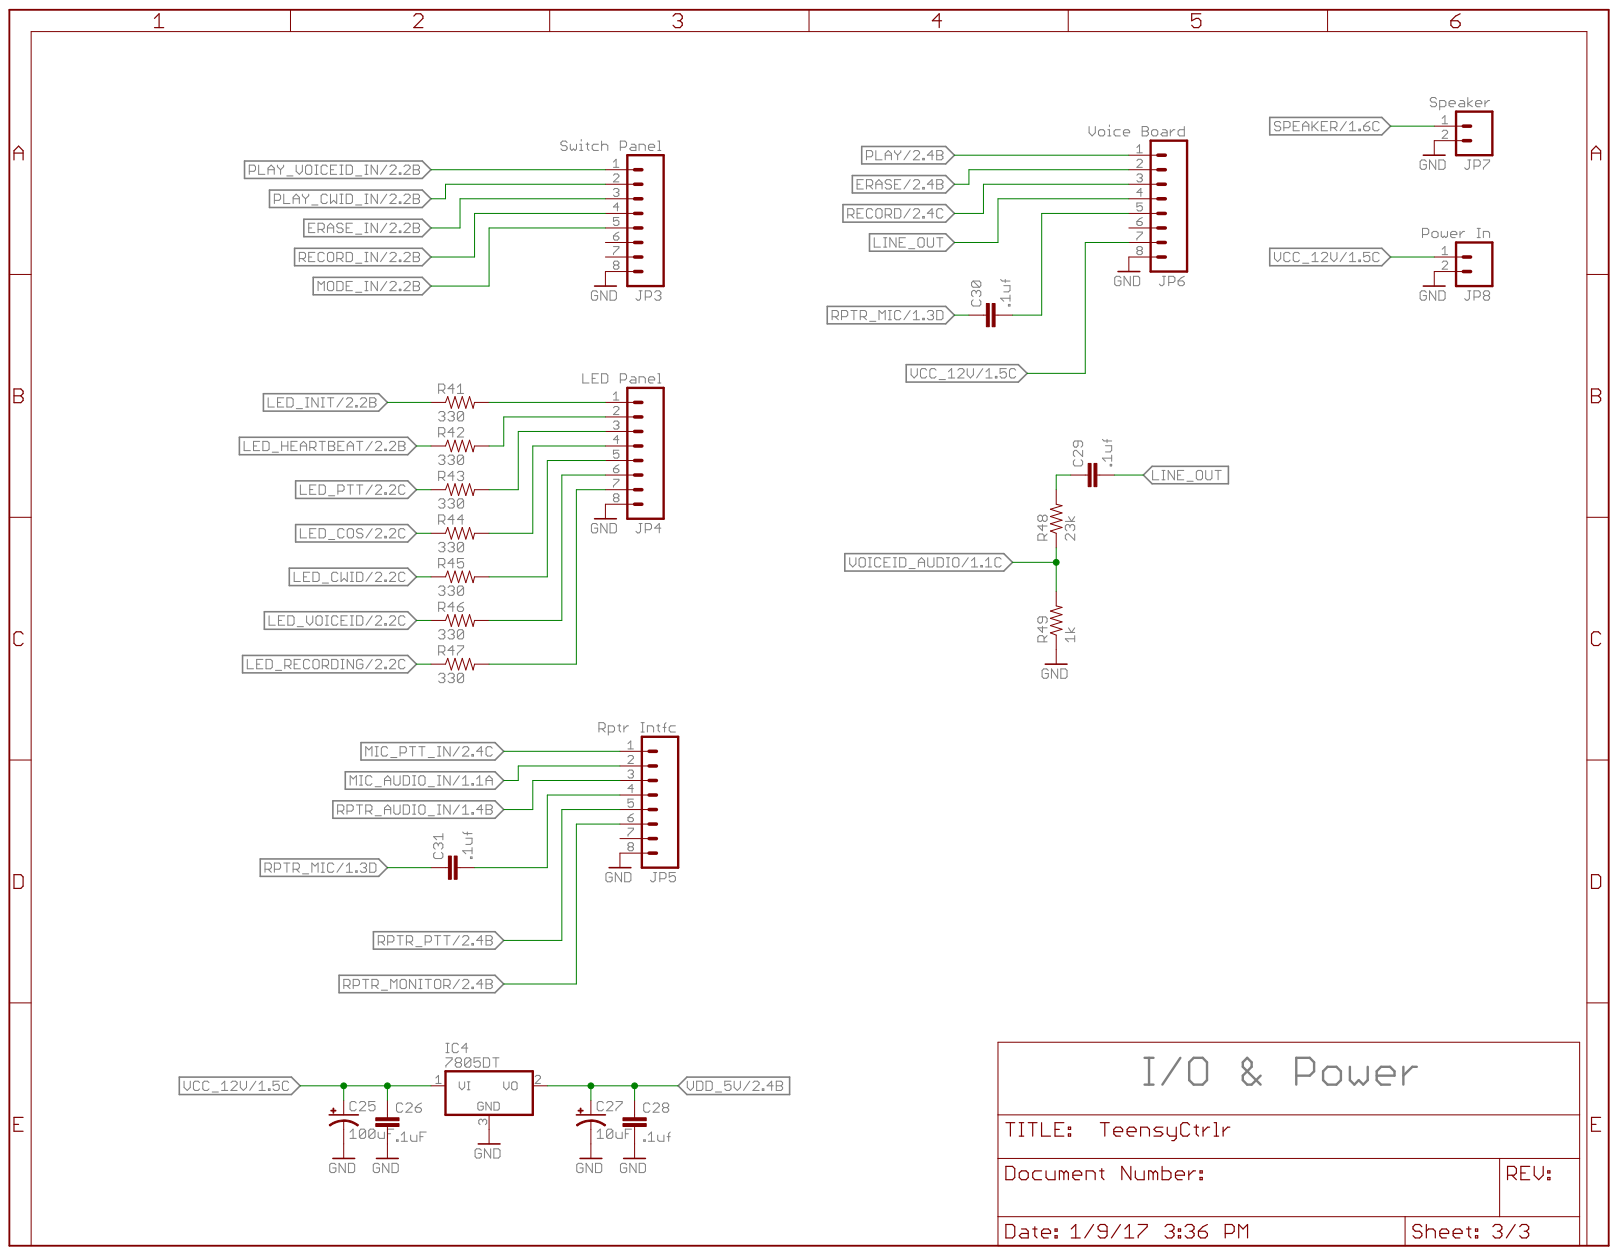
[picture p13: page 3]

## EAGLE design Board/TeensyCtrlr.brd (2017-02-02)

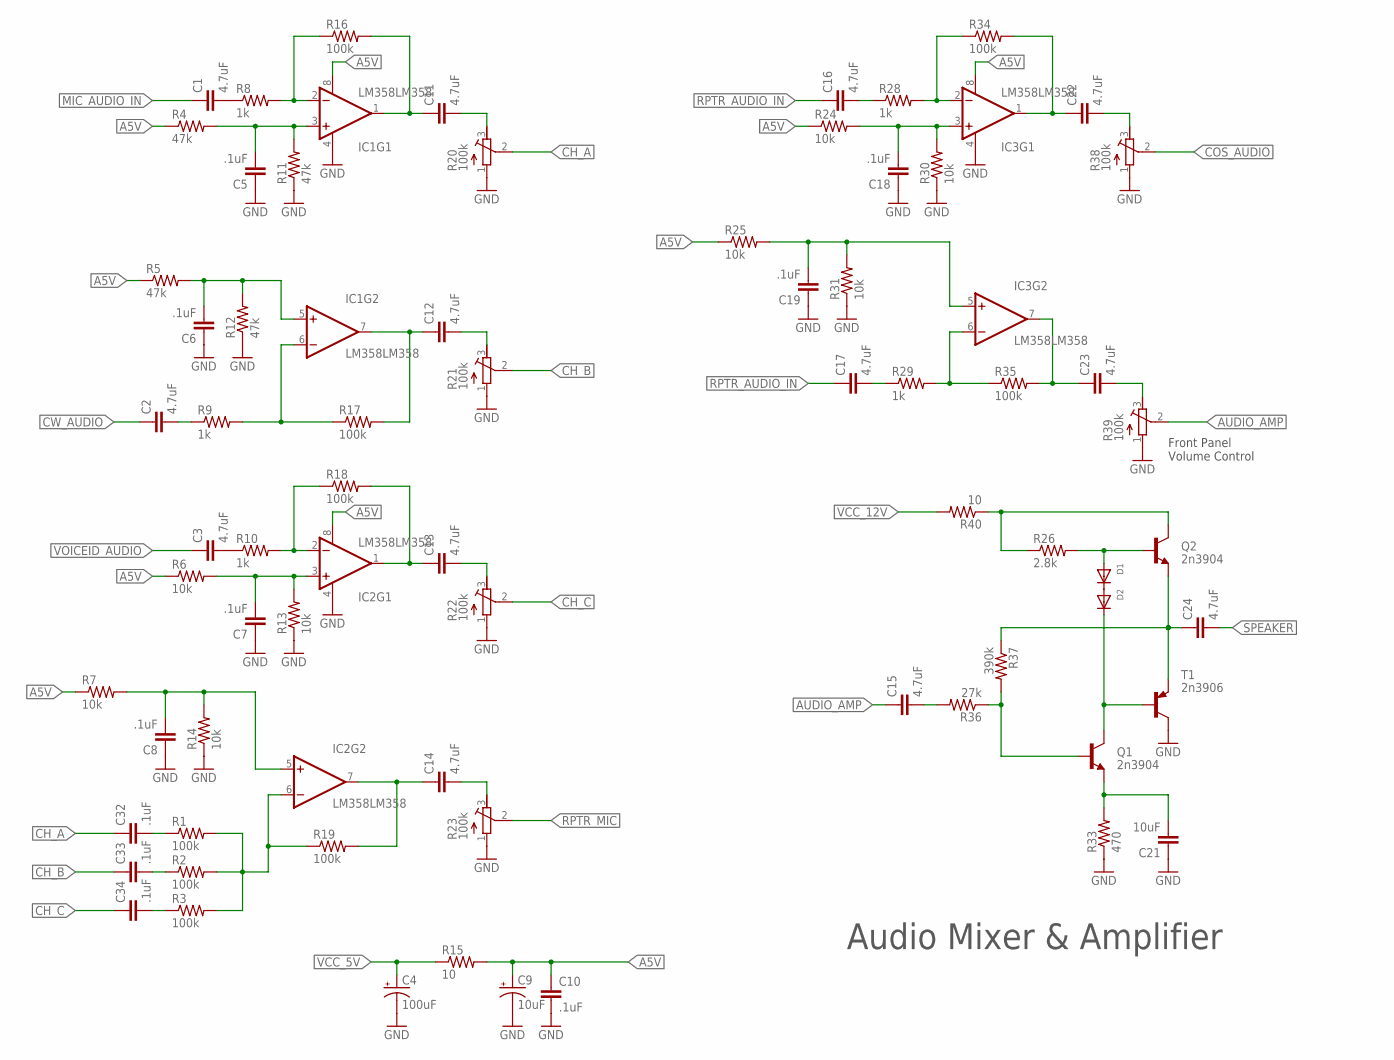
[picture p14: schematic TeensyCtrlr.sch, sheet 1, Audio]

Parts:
C1, C2, C3, C11, C12, C13, C14, C16, C17, C22, C23: 4.7uF; CAP-PTH-SMALL2
C4: 100uF; CPOL-RADIAL-10UF-25V
C5, C6, C7, C8, C10, C18, C19, C32, C33, C34: .1uF; 0805
C9: 10uF; CPOL-RADIAL-100UF-25V
C15, C24: 4.7uF; CAP-PTH-SMALL
C21: 10uF; CAP-PTH-SMALL
D1, D2: DIODEDO-1N4148; DO-1N4148
IC1, IC2, IC3: LM358LM358; SOIC8
Q1, Q2: 2n3904; TO-92-AMMO
R1, R2, R3, R16, R17, R18, R19, R34, R35: 100k; 0805
R4, R5, R11, R12: 47k; 0805
R6, R7, R13, R14, R24, R25, R30, R31: 10k; 0805
R8, R9, R10, R28, R29: 1k; 0805
R15, R40: 10; 0805
R20, R21, R22, R23, R38, R39: 100k; RTRIM3339P
R26: 2.8k; 0805
R33: 470; 0805
R36: 27k; 0805
R37: 390k; 0805
T1: 2n3906; TO92-EBC

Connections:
A5V: C9.1 (+), C10.1, IC1.8 (V+), IC2.8 (V+), IC3.8 (V+), R4.1, R5.1, R6.1, R7.1, R15.2, R24.1, R25.1
AUDIO_AMP: C15.1, R39.2 (S)
CH_A: C32.1, R20.2 (S)
CH_B: C33.1, R21.2 (S)
CH_C: C34.1, R22.2 (S)
COS_AUDIO: R38.2 (S); also elsewhere on the board
CW_AUDIO: C2.1; also elsewhere on the board
GND: C4.2 (-), C5.1, C6.1, C7.1, C8.1, C9.2 (-), C10.2, C18.1, C19.1, C21.1, IC1.4 (V-), IC2.4 (V-), IC3.4 (V-), R11.1, R12.1, R13.1, R14.1, R20.1 (A), R21.1 (A), R22.1 (A), R23.1 (A), R30.1, R31.1, R33.1, R38.1 (A), R39.1 (A), T1.C; also elsewhere on the board
MIC_AUDIO_IN: C1.1; also elsewhere on the board
unnamed: IC1.2 (-IN), R8.2, R16.1
unnamed: C5.2, IC1.3 (+IN), R4.2, R11.2
unnamed: C1.2, R8.1
unnamed: C11.2, R20.3 (E)
unnamed: IC1.6 (-IN), R9.2, R17.1
unnamed: C11.1, IC1.1 (OUT), R16.2
unnamed: IC2.2 (-IN), R10.2, R18.1
unnamed: C6.2, IC1.5 (+IN), R5.2, R12.2
unnamed: C2.2, R9.1
unnamed: C12.1, IC1.7 (OUT), R17.2
unnamed: C12.2, R21.3 (E)
unnamed: C7.2, IC2.3 (+IN), R6.2, R13.2
unnamed: C3.2, R10.1
unnamed: C13.1, IC2.1 (OUT), R18.2
unnamed: C13.2, R22.3 (E)
unnamed: IC2.6 (-IN), R1.2, R2.2, R3.2, R19.1
unnamed: C8.2, IC2.5 (+IN), R7.2, R14.2
unnamed: C15.2, R36.2
unnamed: C14.1, IC2.7 (OUT), R19.2
unnamed: C14.2, R23.3 (E)
unnamed: Q2.3 (C), R26.1, R40.1
unnamed: IC3.2 (-IN), R28.2, R34.1
unnamed: C21.2, Q1.1 (E), R33.2
unnamed: C18.2, IC3.3 (+IN), R24.2, R30.2
unnamed: C16.2, R28.1
unnamed: C22.1, IC3.1 (OUT), R34.2
unnamed: C22.2, R38.3 (E)
unnamed: IC3.6 (-IN), R29.2, R35.1
unnamed: C19.2, IC3.5 (+IN), R25.2, R31.2
unnamed: C17.2, R29.1
unnamed: C23.1, IC3.7 (OUT), R35.2
unnamed: C23.2, R39.3 (E)
unnamed: C24.1, Q2.1 (E), R37.1, T1.E
unnamed: D1.C, D2.A
unnamed: D1.A, Q2.2 (B), R26.2
unnamed: D2.C, Q1.3 (C), T1.B
unnamed: C32.2, R1.1
unnamed: C33.2, R2.1
unnamed: C34.2, R3.1
unnamed: Q1.2 (B), R36.1, R37.2
RPTR_AUDIO_IN: C16.1, C17.1; also elsewhere on the board
RPTR_MIC: R23.2 (S); also elsewhere on the board
SPEAKER: C24.2; also elsewhere on the board
VCC_5V: C4.1 (+), R15.1
VCC_12V: R40.2; also elsewhere on the board
VOICEID_AUDIO: C3.1; also elsewhere on the board

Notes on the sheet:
Audio Mixer & Amplifier
Front Panel Volume Control

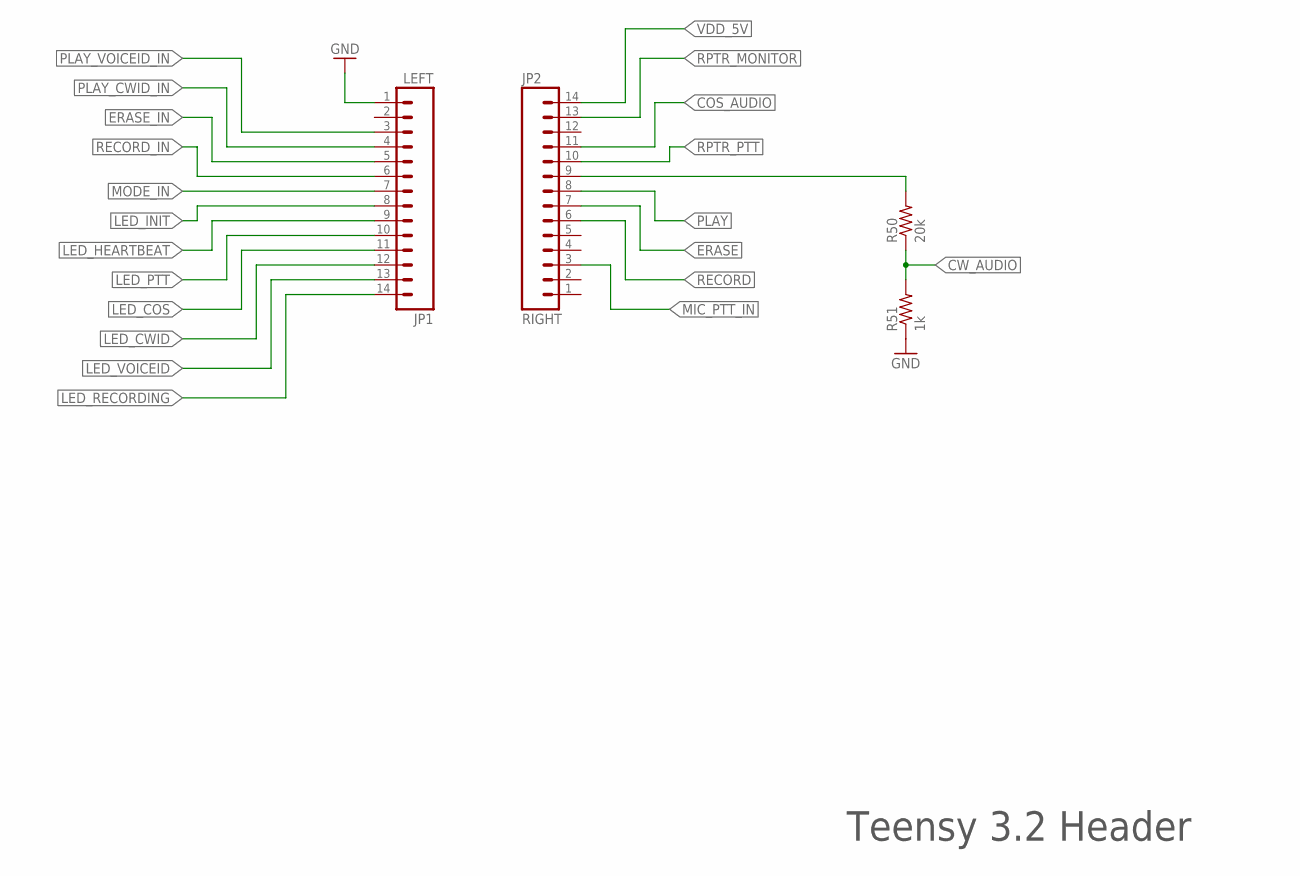
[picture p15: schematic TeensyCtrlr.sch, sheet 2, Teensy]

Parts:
JP1: LEFT; 1X14-LONGPADS
JP2: RIGHT; 1X14-LONGPADS
R50: 20k; 0805
R51: 1k; 0805

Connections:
COS_AUDIO: JP2.11; also elsewhere on the board
CW_AUDIO: R50.1, R51.2; also elsewhere on the board
ERASE: JP2.7; also elsewhere on the board
ERASE_IN: JP1.5; also elsewhere on the board
GND: JP1.1, R51.1; also elsewhere on the board
LED_COS: JP1.11; also elsewhere on the board
LED_CWID: JP1.12; also elsewhere on the board
LED_HEARTBEAT: JP1.9; also elsewhere on the board
LED_INIT: JP1.8; also elsewhere on the board
LED_PTT: JP1.10; also elsewhere on the board
LED_RECORDING: JP1.14; also elsewhere on the board
LED_VOICEID: JP1.13; also elsewhere on the board
MIC_PTT_IN: JP2.3; also elsewhere on the board
MODE_IN: JP1.7; also elsewhere on the board
unnamed: JP2.9, R50.2
PLAY: JP2.8; also elsewhere on the board
PLAY_CWID_IN: JP1.4; also elsewhere on the board
PLAY_VOICEID_IN: JP1.3; also elsewhere on the board
RECORD: JP2.6; also elsewhere on the board
RECORD_IN: JP1.6; also elsewhere on the board
RPTR_MONITOR: JP2.13; also elsewhere on the board
RPTR_PTT: JP2.10; also elsewhere on the board
VDD_5V: JP2.14; also elsewhere on the board

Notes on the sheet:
Teensy 3.2 Header

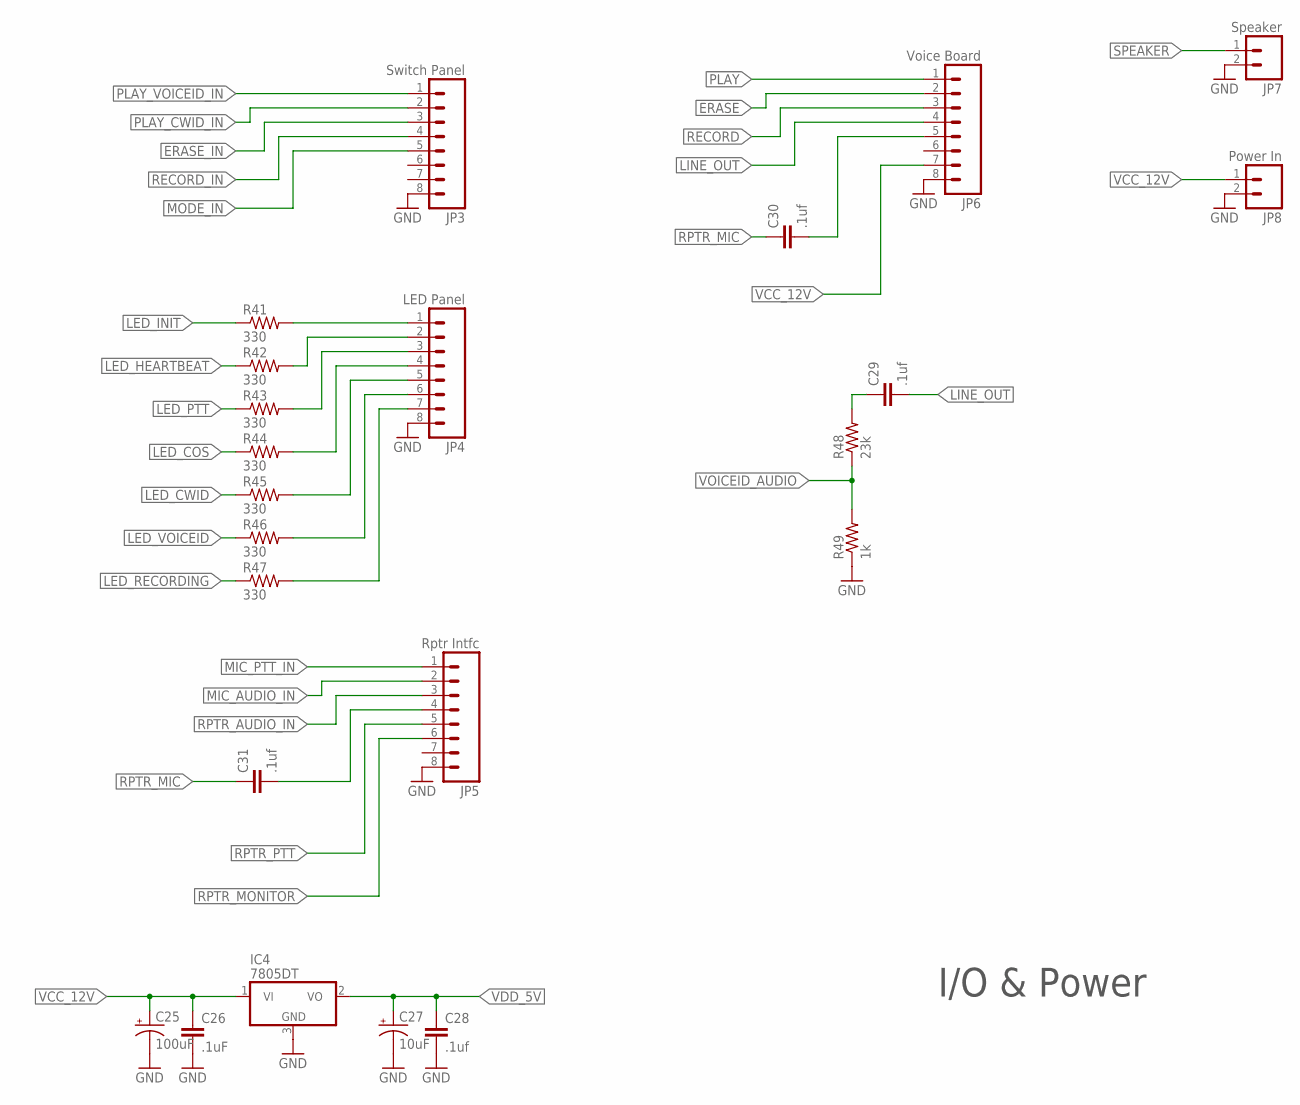
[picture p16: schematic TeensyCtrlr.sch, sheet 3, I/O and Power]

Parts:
C25: 100uF; CPOL-RADIAL-1000UF-25V
C26: .1uF; 0805
C27: 10uF; CPOL-RADIAL-100UF-25V
C28, C29, C30, C31: .1uf; 0805
IC4: 7805DT; TO252
JP3: Switch Panel; 1X08_LONGPADS
JP4: LED Panel; 1X08_LONGPADS
JP5: Rptr Intfc; 1X08_LONGPADS
JP6: Voice Board; 1X08_LONGPADS
JP7: Speaker; 1X02_LONGPADS
JP8: Power In; 1X02_LONGPADS
R41, R42, R43, R44, R45, R46, R47: 330; 0805
R48: 23k; 0805
R49: 1k; 0805

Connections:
ERASE: JP6.2; also elsewhere on the board
ERASE_IN: JP3.3; also elsewhere on the board
GND: C25.-, C26.2, C27.2 (-), C28.2, IC4.3 (GND), JP3.8, JP4.8, JP5.8, JP6.8, JP7.2, JP8.2, R49.1; also elsewhere on the board
LED_COS: R44.1; also elsewhere on the board
LED_CWID: R45.1; also elsewhere on the board
LED_HEARTBEAT: R42.1; also elsewhere on the board
LED_INIT: R41.1; also elsewhere on the board
LED_PTT: R43.1; also elsewhere on the board
LED_RECORDING: R47.1; also elsewhere on the board
LED_VOICEID: R46.1; also elsewhere on the board
LINE_OUT: C29.2, JP6.4
MIC_AUDIO_IN: JP5.2; also elsewhere on the board
MIC_PTT_IN: JP5.1; also elsewhere on the board
MODE_IN: JP3.5; also elsewhere on the board
unnamed: JP4.1, R41.2
unnamed: JP4.2, R42.2
unnamed: JP4.3, R43.2
unnamed: JP4.4, R44.2
unnamed: JP4.5, R45.2
unnamed: JP4.6, R46.2
unnamed: JP4.7, R47.2
unnamed: C31.2, JP5.4
unnamed: C30.2, JP6.5
unnamed: C29.1, R48.2
PLAY: JP6.1; also elsewhere on the board
PLAY_CWID_IN: JP3.2; also elsewhere on the board
PLAY_VOICEID_IN: JP3.1; also elsewhere on the board
RECORD: JP6.3; also elsewhere on the board
RECORD_IN: JP3.4; also elsewhere on the board
RPTR_AUDIO_IN: JP5.3; also elsewhere on the board
RPTR_MIC: C30.1, C31.1; also elsewhere on the board
RPTR_MONITOR: JP5.6; also elsewhere on the board
RPTR_PTT: JP5.5; also elsewhere on the board
SPEAKER: JP7.1; also elsewhere on the board
VCC_12V: C25.+, C26.1, IC4.1 (VI), JP6.7, JP8.1; also elsewhere on the board
VDD_5V: C27.1 (+), C28.1, IC4.2 (VO); also elsewhere on the board
VOICEID_AUDIO: R48.1, R49.2; also elsewhere on the board

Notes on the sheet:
I/O & Power

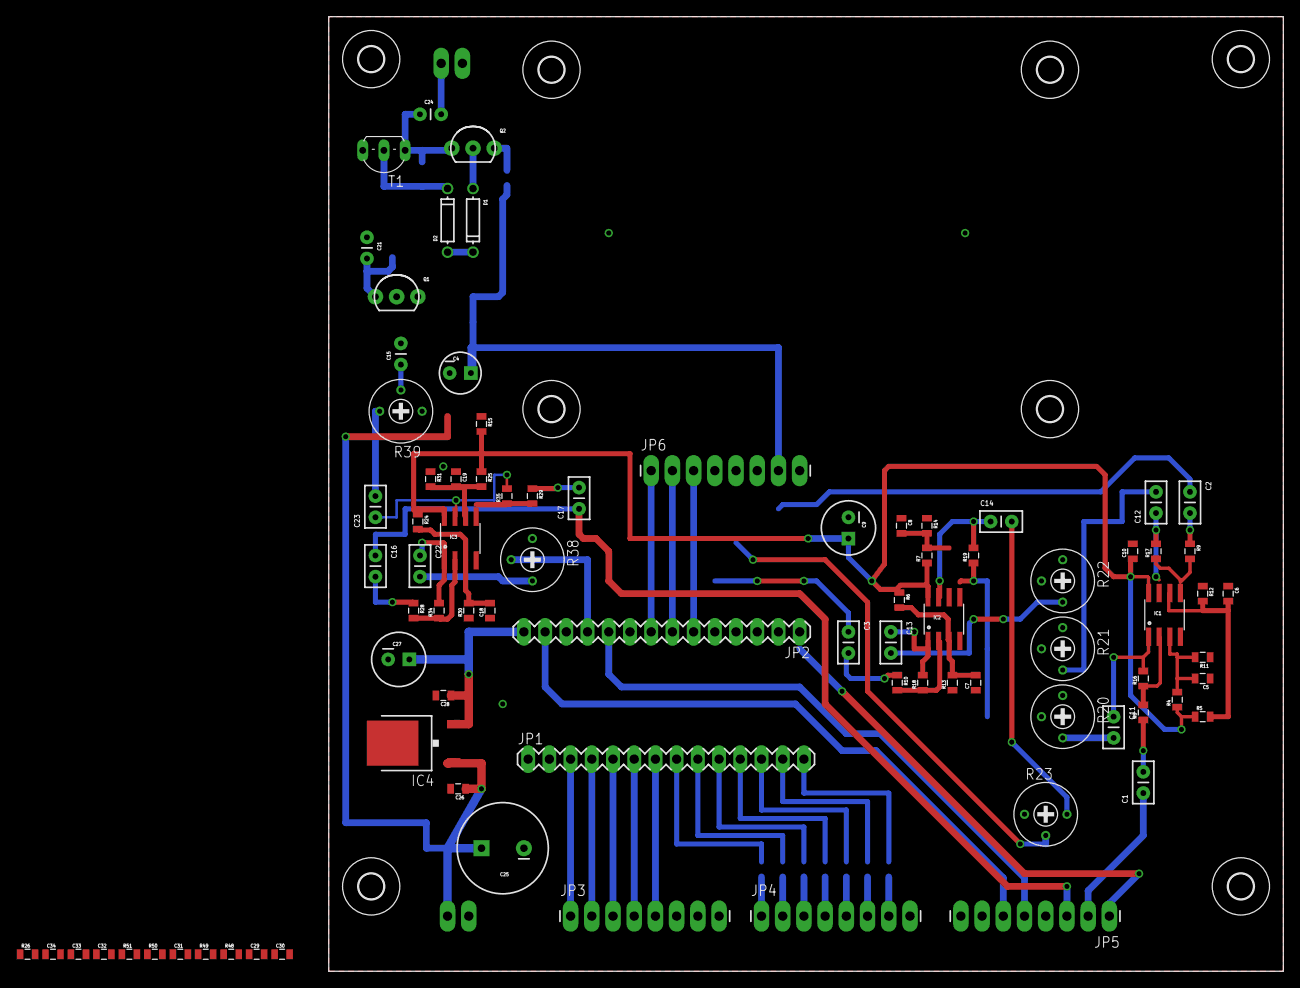
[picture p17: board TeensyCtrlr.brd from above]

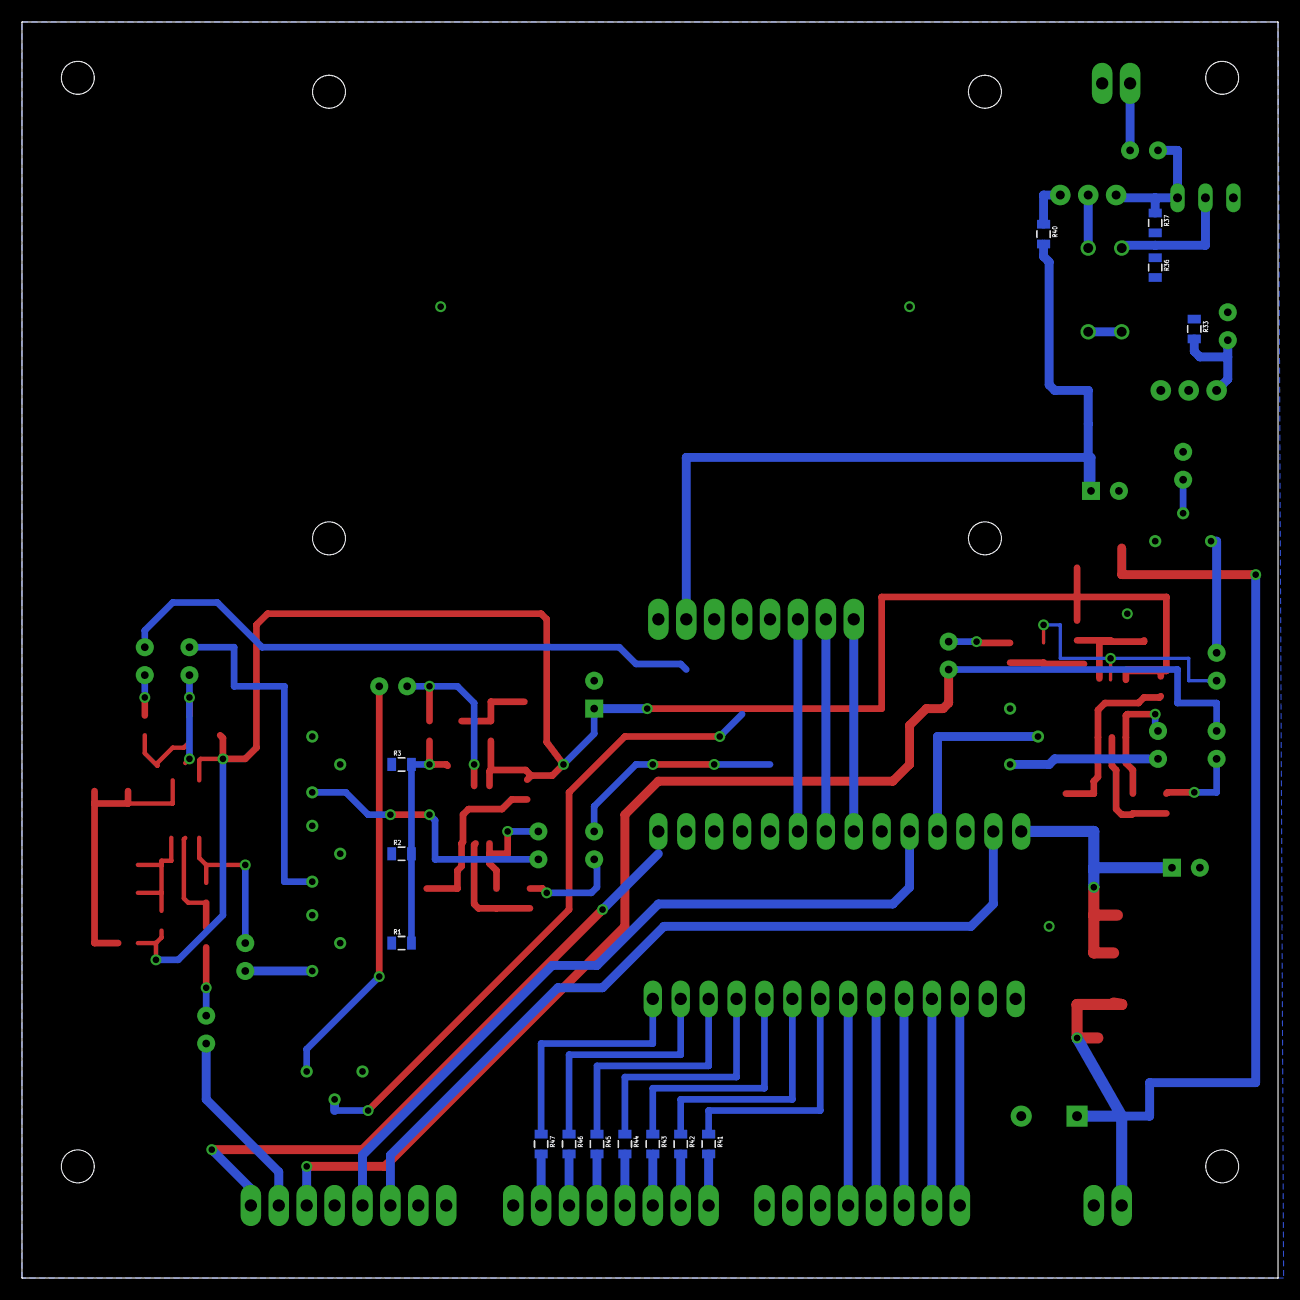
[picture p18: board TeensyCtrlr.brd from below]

Board: 2 copper layers, 114.3 x 114.3 mm, 107 parts (14 on the bottom side), 86 nets.

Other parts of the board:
U$1, U$2, U$3, U$4, U$5, U$6, U$7, U$8: 3,0

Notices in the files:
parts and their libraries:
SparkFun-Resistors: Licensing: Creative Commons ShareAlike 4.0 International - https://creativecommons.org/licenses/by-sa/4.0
